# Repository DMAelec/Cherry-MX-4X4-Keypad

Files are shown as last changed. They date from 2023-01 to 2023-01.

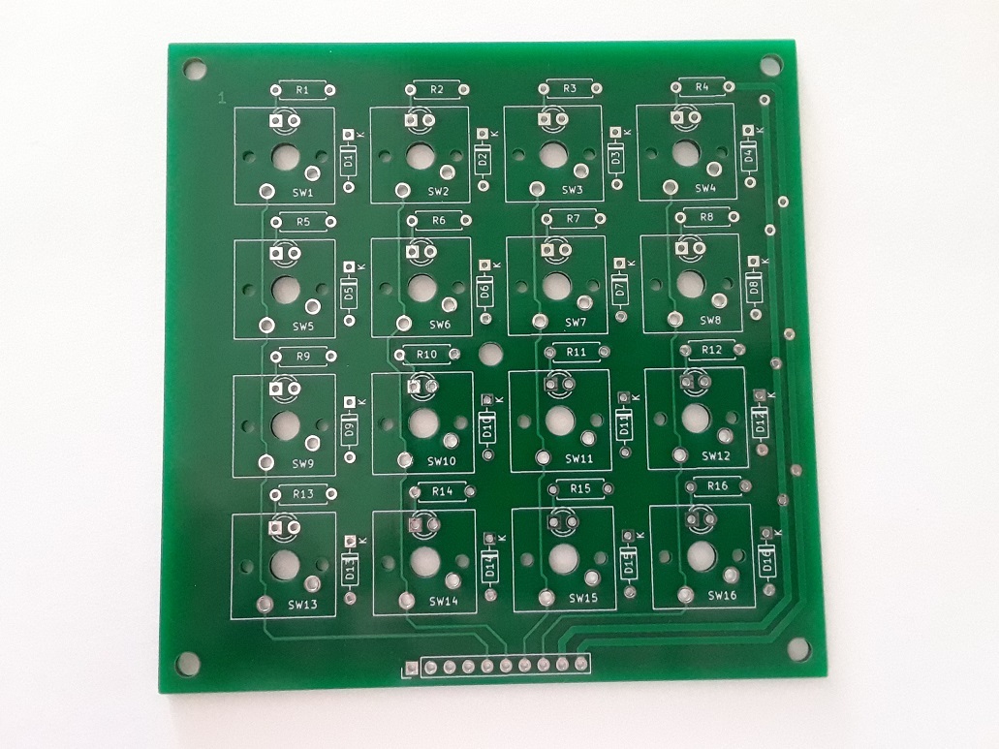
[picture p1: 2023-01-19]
pics/MX4X4KEYPAD2.jpg

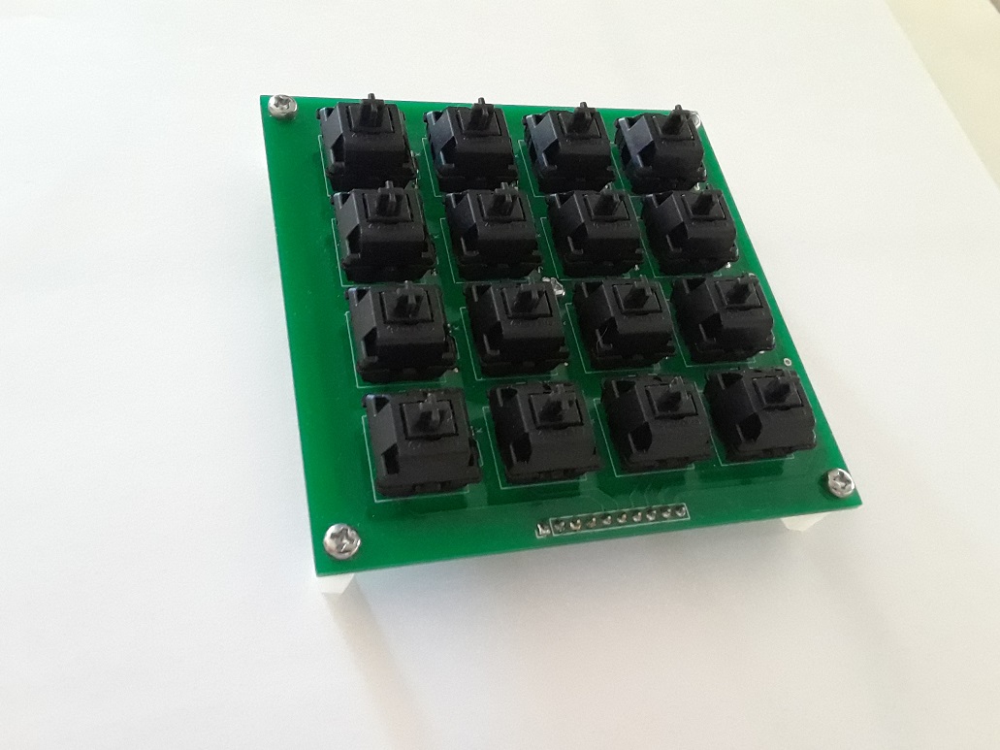
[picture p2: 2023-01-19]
pics/MX4X4KEYPAD1.jpg

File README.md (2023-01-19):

# Cherry MX 4X4 Keypad
A simple 16 key mechanical keypad designed for use with microcontrollers. This keypad is similar to the membrane 
ones used in Arduino projects but instead using Cherry MX switches with backlighting. You can use interface this
with Arduinos or Raspberry Pi, or even use it on a more advanced microcontroller like the teensy or the pro micro 
and load up QMK for a custom macropad.
 
Completely through hole PCB with provisions for 3mm LED backlighting and for NKRO diodes. Designed with Kicad 5.1 and 
files include schematic and drill template for mounting holes.

NOTE: If using NKRO diodes some Arduino sketches won't register keys unless you modify the code or insert the diodes backwards.

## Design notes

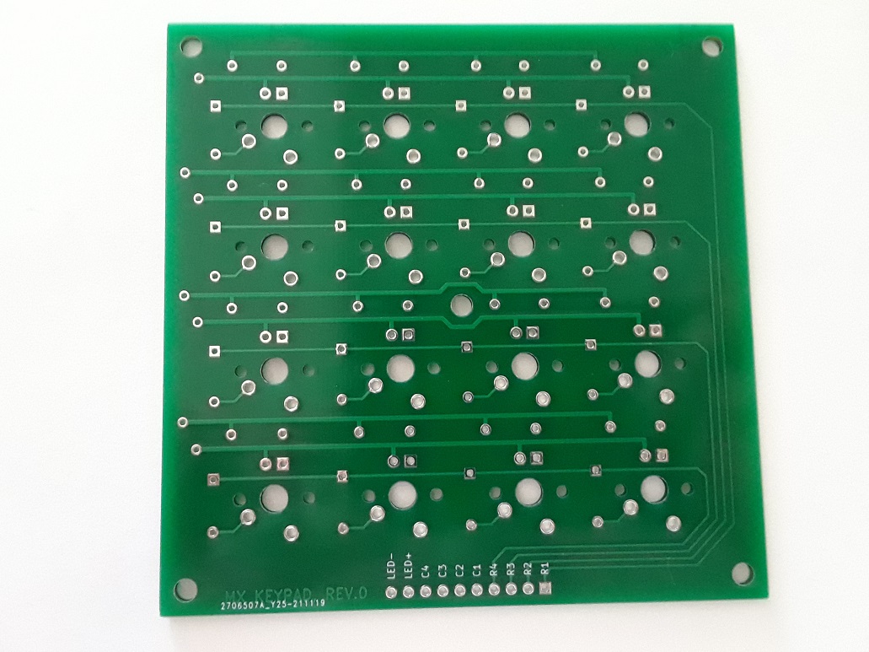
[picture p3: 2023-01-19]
pics/MX4X4KEYPAD3.jpg

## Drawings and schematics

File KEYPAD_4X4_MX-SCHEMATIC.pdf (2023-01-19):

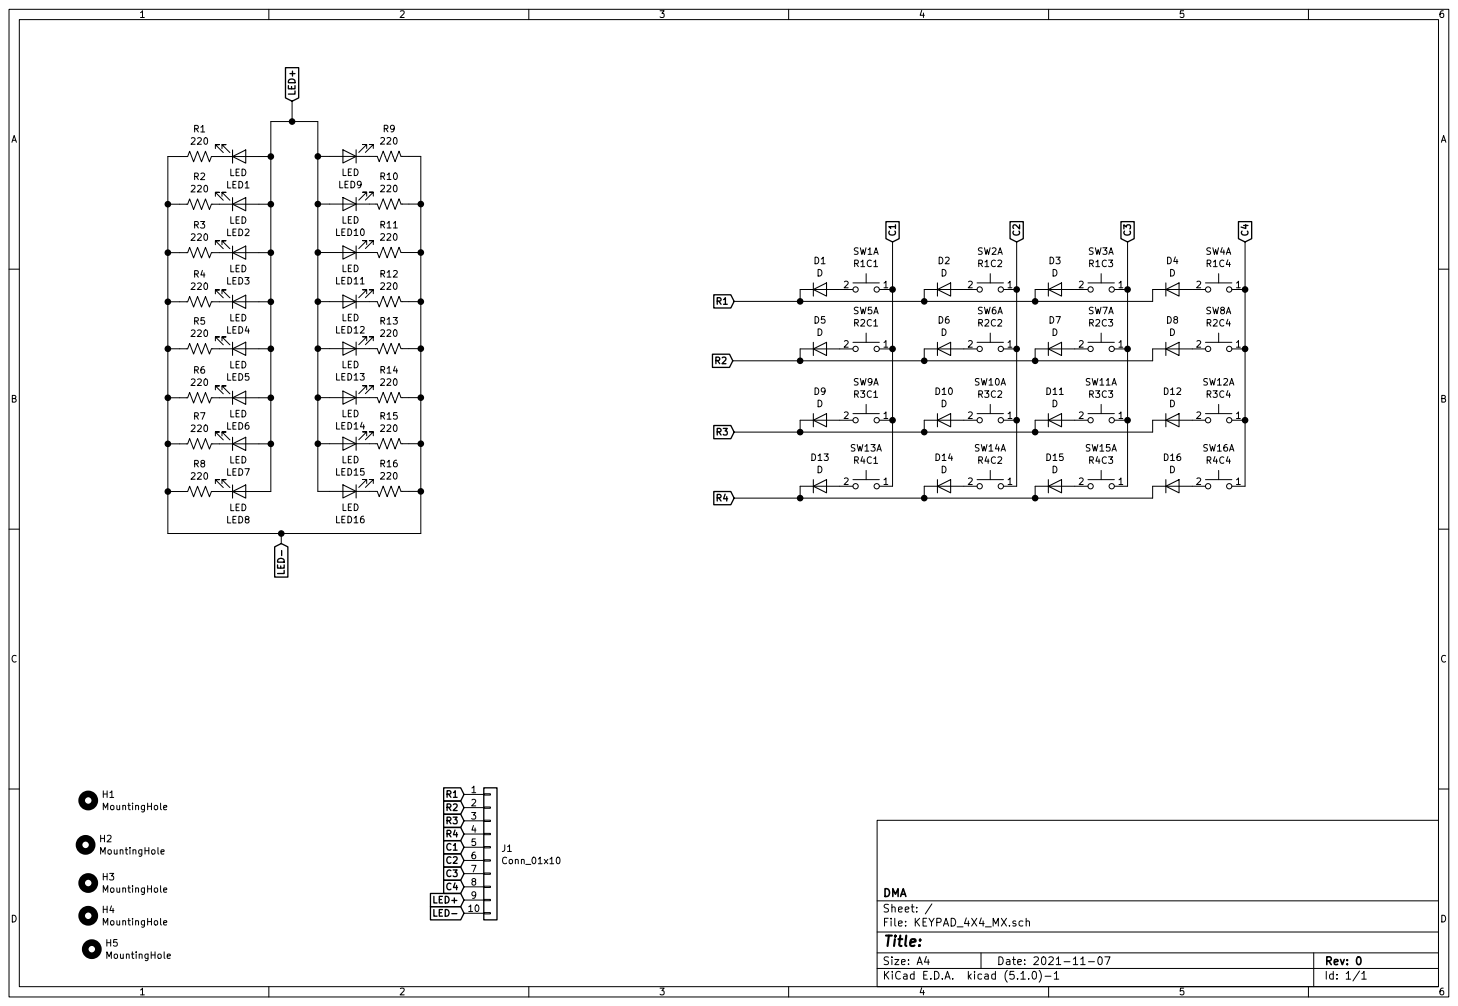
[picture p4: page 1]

File: KEYPAD_4X4_MX.sch Sheet: / DMA

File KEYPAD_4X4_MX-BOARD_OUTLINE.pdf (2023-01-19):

2

1

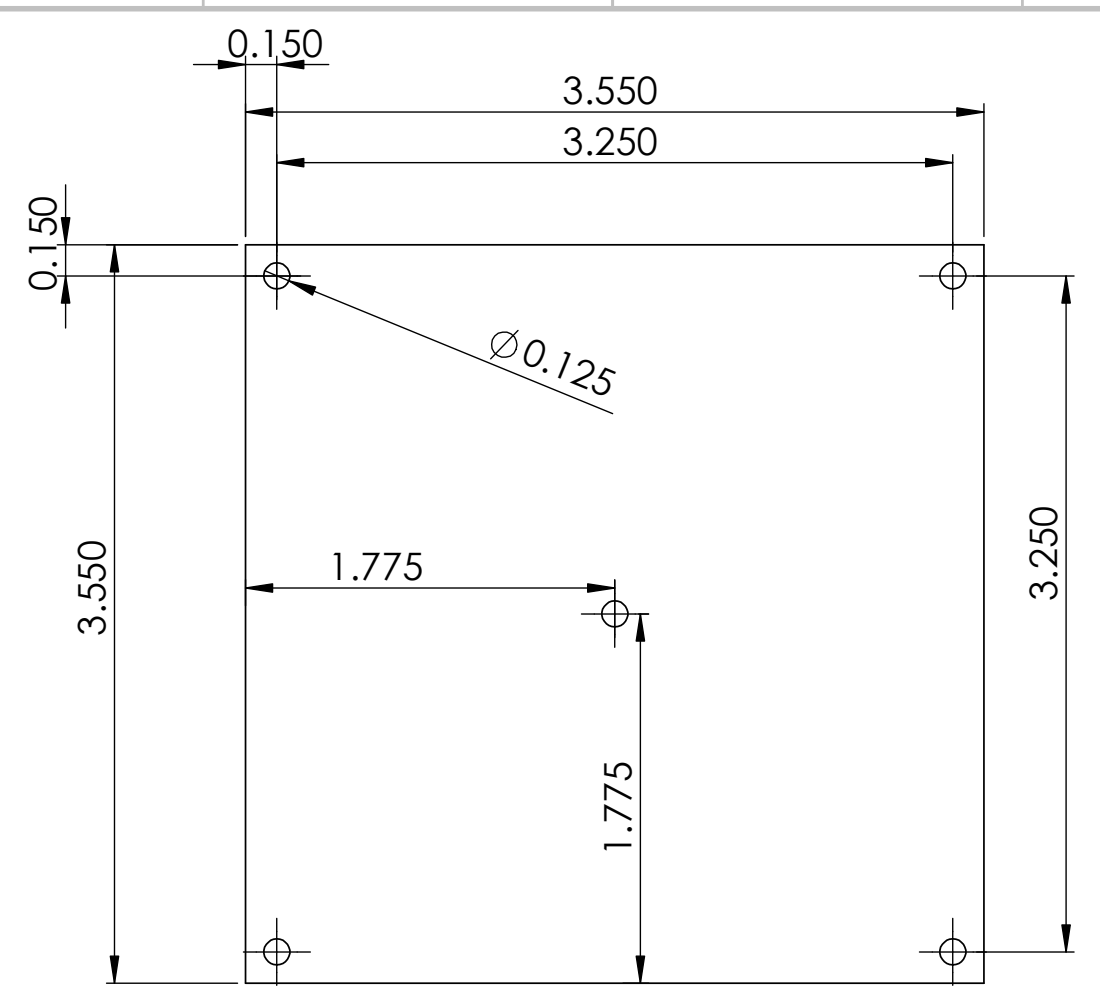
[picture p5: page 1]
SHEET 1 OF 1; WEIGHT:; DWG NO.; SCALE:1:1; 4x4KEYPAD_BOARD_OUTLINE

SOLIDWORKS Educational Product. For Instructional Use Only.

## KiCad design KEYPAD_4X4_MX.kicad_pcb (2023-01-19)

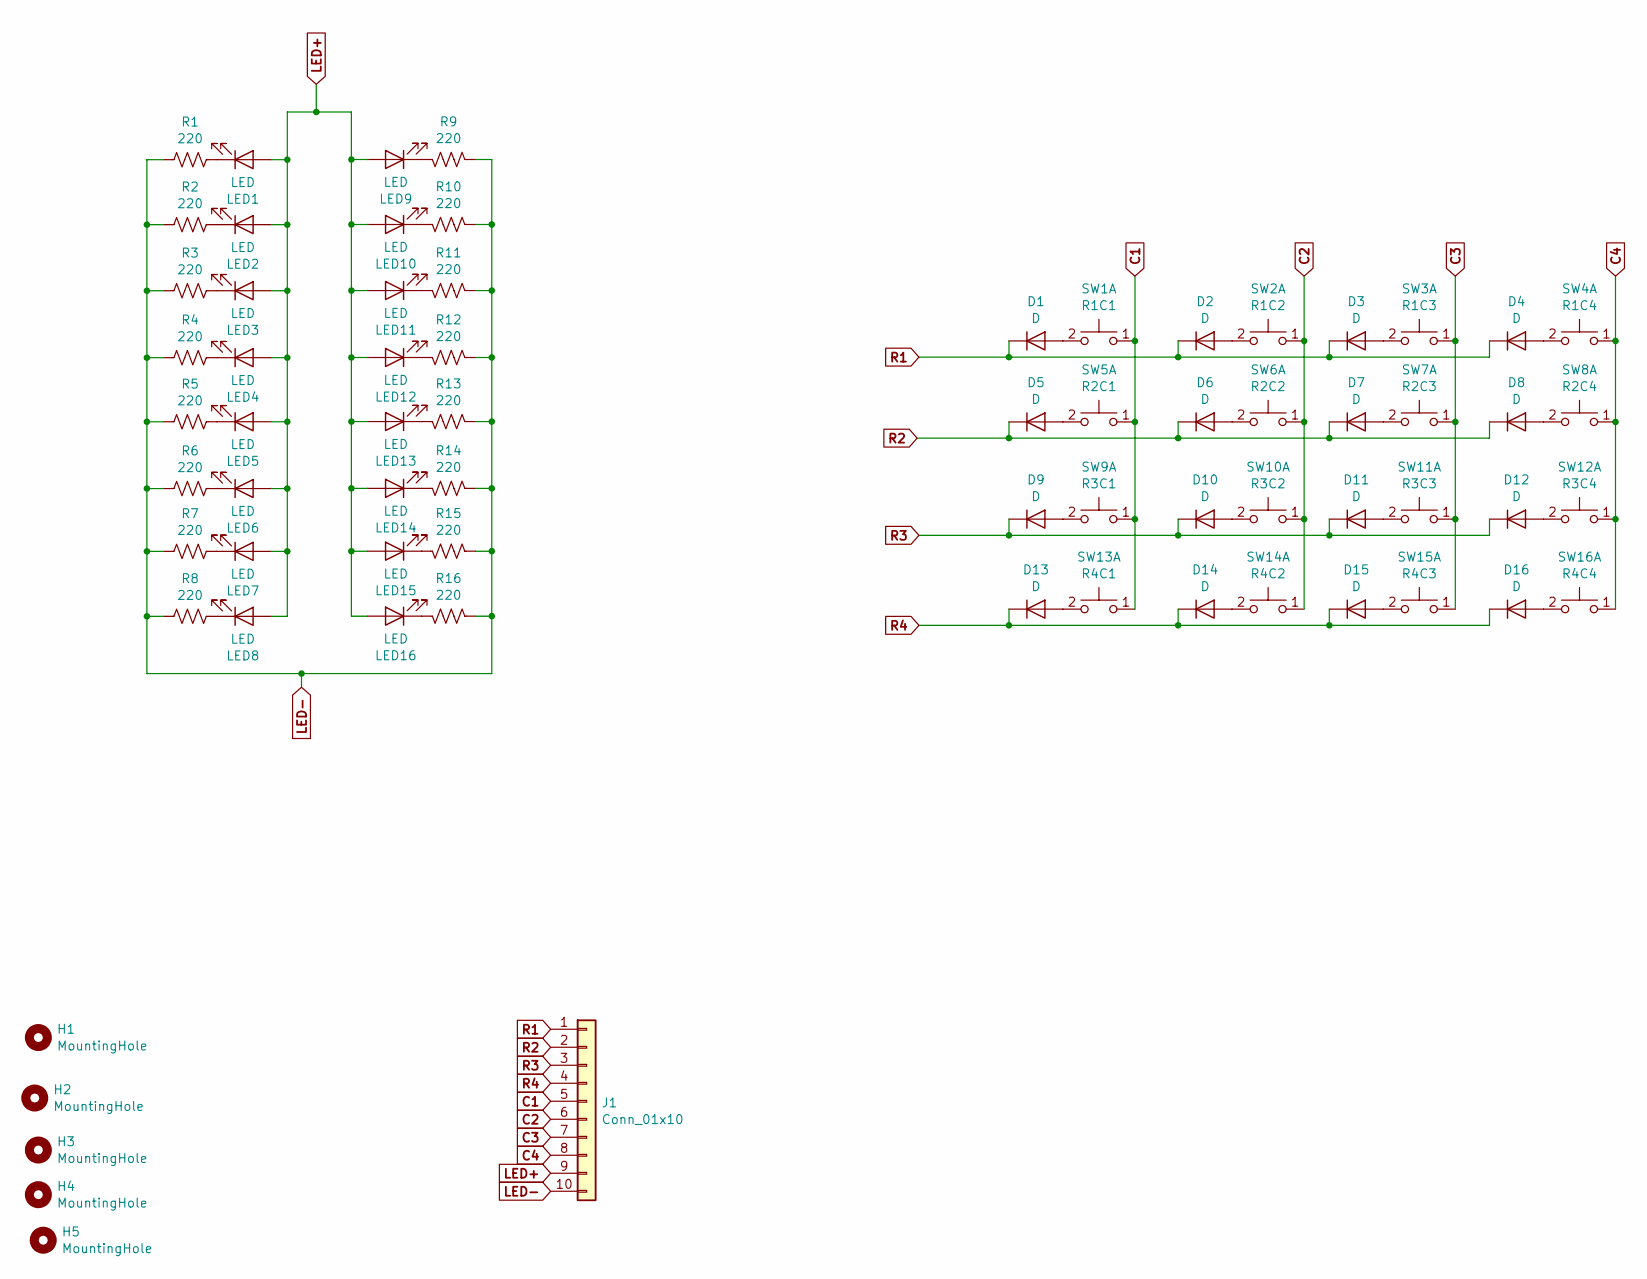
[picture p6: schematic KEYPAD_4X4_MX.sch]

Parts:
D1, D2, D3, D4, D5, D6, D7, D8, D9, D10, D11, D12, D13, D14, D15, D16: D; D_DO-35_SOD27_P7.62mm_Horizontal
H1, H2, H3, H4, H5: MountingHole; MountingHole_3.2mm_M3
J1: Conn_01x10; PinHeader_1x10_P2.54mm_Vertical
LED1, LED2, LED3, LED4, LED5, LED6, LED7, LED8, LED9, LED10, LED11, LED12, LED13, LED14, LED15, LED16: LED; LED_D3.0mm
R1, R2, R3, R4, R5, R6, R7, R8, R9, R10, R11, R12, R13, R14, R15, R16: 220; R_Axial_DIN0207_L6.3mm_D2.5mm_P7.62mm_Horizontal
SW1: R1C1; SW_Cherry_MX1A_1.00u_PCB
SW2: R1C2; SW_Cherry_MX1A_1.00u_PCB
SW3: R1C3; SW_Cherry_MX1A_1.00u_PCB
SW4: R1C4; SW_Cherry_MX1A_1.00u_PCB
SW5: R2C1; SW_Cherry_MX1A_1.00u_PCB
SW6: R2C2; SW_Cherry_MX1A_1.00u_PCB
SW7: R2C3; SW_Cherry_MX1A_1.00u_PCB
SW8: R2C4; SW_Cherry_MX1A_1.00u_PCB
SW9: R3C1; SW_Cherry_MX1A_1.00u_PCB
SW10: R3C2; SW_Cherry_MX1A_1.00u_PCB
SW11: R3C3; SW_Cherry_MX1A_1.00u_PCB
SW12: R3C4; SW_Cherry_MX1A_1.00u_PCB
SW13: R4C1; SW_Cherry_MX1A_1.00u_PCB
SW14: R4C2; SW_Cherry_MX1A_1.00u_PCB
SW15: R4C3; SW_Cherry_MX1A_1.00u_PCB
SW16: R4C4; SW_Cherry_MX1A_1.00u_PCB

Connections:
C1: J1.5, SW1.1 (C), SW5.1 (C), SW9.1 (C), SW13.1 (C)
C2: J1.6, SW2.1 (C), SW6.1 (C), SW10.1 (C), SW14.1 (C)
C3: J1.7, SW3.1 (C), SW7.1 (C), SW11.1 (C), SW15.1 (C)
C4: J1.8, SW4.1 (C), SW8.1 (C), SW12.1 (C), SW16.1 (C)
LED+: J1.9, LED1.2 (A), LED2.2 (A), LED3.2 (A), LED4.2 (A), LED5.2 (A), LED6.2 (A), LED7.2 (A), LED8.2 (A), LED9.2 (A), LED10.2 (A), LED11.2 (A), LED12.2 (A), LED13.2 (A), LED14.2 (A), LED15.2 (A), LED16.2 (A)
LED-: J1.10, R1.2, R2.2, R3.2, R4.2, R5.2, R6.2, R7.2, R8.2, R9.2, R10.2, R11.2, R12.2, R13.2, R14.2, R15.2, R16.2
unnamed: D1.2 (A), SW1.2 (D)
unnamed: D2.2 (A), SW2.2 (D)
unnamed: D3.2 (A), SW3.2 (D)
unnamed: D4.2 (A), SW4.2 (D)
unnamed: D5.2 (A), SW5.2 (D)
unnamed: D6.2 (A), SW6.2 (D)
unnamed: D7.2 (A), SW7.2 (D)
unnamed: D8.2 (A), SW8.2 (D)
unnamed: D9.2 (A), SW9.2 (D)
unnamed: D10.2 (A), SW10.2 (D)
unnamed: D11.2 (A), SW11.2 (D)
unnamed: D12.2 (A), SW12.2 (D)
unnamed: D13.2 (A), SW13.2 (D)
unnamed: D14.2 (A), SW14.2 (D)
unnamed: D15.2 (A), SW15.2 (D)
unnamed: D16.2 (A), SW16.2 (D)
unnamed: LED1.1 (K), R1.1
unnamed: LED2.1 (K), R2.1
unnamed: LED3.1 (K), R3.1
unnamed: LED4.1 (K), R4.1
unnamed: LED5.1 (K), R5.1
unnamed: LED6.1 (K), R6.1
unnamed: LED7.1 (K), R7.1
unnamed: LED8.1 (K), R8.1
unnamed: LED9.1 (K), R9.1
unnamed: LED10.1 (K), R10.1
unnamed: LED11.1 (K), R11.1
unnamed: LED12.1 (K), R12.1
unnamed: LED13.1 (K), R13.1
unnamed: LED14.1 (K), R14.1
unnamed: LED15.1 (K), R15.1
unnamed: LED16.1 (K), R16.1
R1: D1.1 (K), D2.1 (K), D3.1 (K), D4.1 (K), J1.1
R2: D5.1 (K), D6.1 (K), D7.1 (K), D8.1 (K), J1.2
R3: D9.1 (K), D10.1 (K), D11.1 (K), D12.1 (K), J1.3
R4: D13.1 (K), D14.1 (K), D15.1 (K), D16.1 (K), J1.4

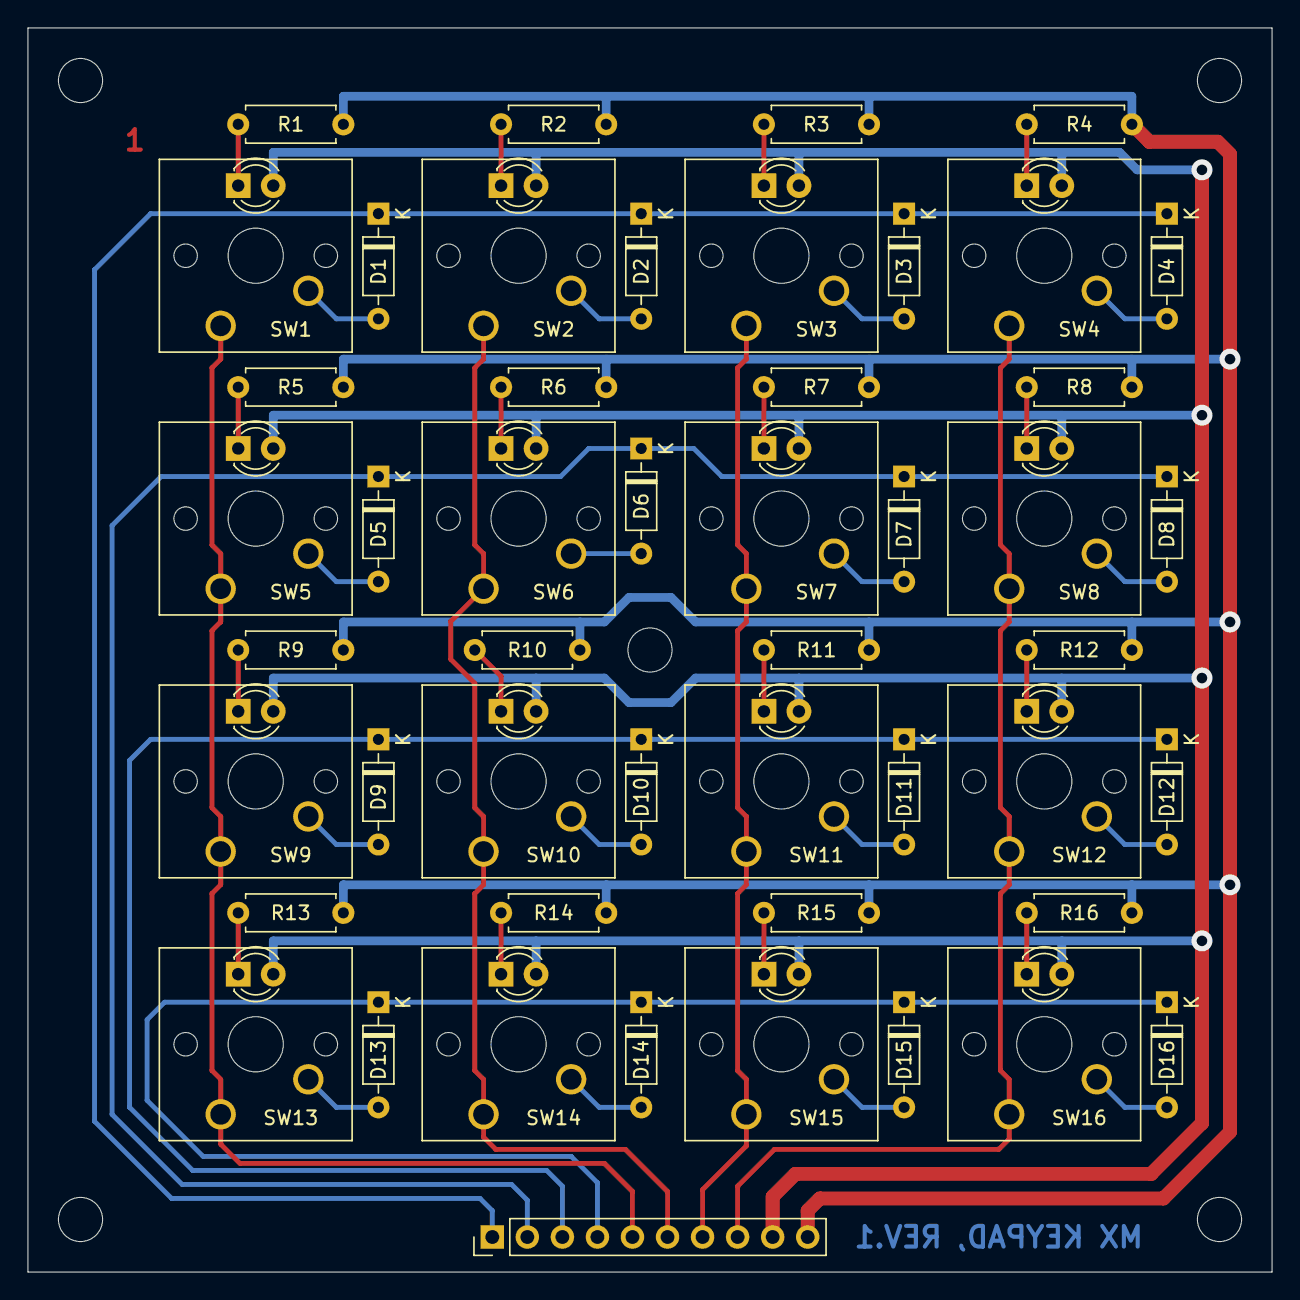
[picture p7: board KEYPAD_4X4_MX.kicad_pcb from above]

Board: 2 copper layers, 90.2 x 90.2 mm, 70 parts (0 on the bottom side), 42 nets.
